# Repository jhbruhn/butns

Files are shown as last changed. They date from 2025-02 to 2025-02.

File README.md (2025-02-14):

# Overview

small grid 64 clone heavily based on previous work by [hugelton/btns](https://github.com/hugelton/Btns).

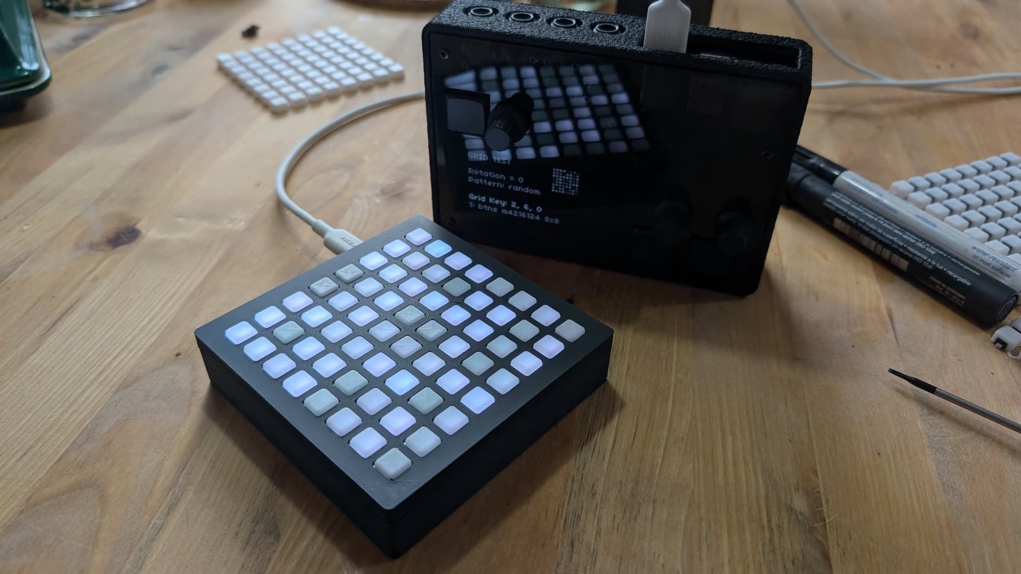
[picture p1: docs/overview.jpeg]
overview image


Uses a Rasperry Pi Pico Microcontroller, NeoPixel RGB LEDs (SK6812), cheap buttons and a 3d-printed case and button-overlay.
Includes hardware and firmware support for an optional tilt-sensor.

# Building

It is highly recommended to order the PCB assembled from JLCPCB. That assembly will include everything other than the parts in the BOM.

## BOM

| Part | Quantity | Source | Required | 
|---|---|---|---|
| PCB with components | 1 | JLCPCB, ordered with Gerber and Assembly files from latest release. Gerber: `butns-JLCPCB.zip`, BOM: `butns_bom_jlc.csv`, CPL: `butns_cpl_jlc.csv`. | yes | 
| Raspberry Pi Pico | 1 | Original Raspberry Pi Pico, or [USB-C Variant](https://de.aliexpress.com/item/1005007393927221.html) | yes | |
| M2.5x6 Button Head Screws | 5 | [M2.5x6](https://www.aliexpress.com/item/32810852732.html) | yes | 
| Case | 1 | 3d-printed (FDM). `case.stl` contains the top and bottom half. In the image, it is printed in black PLA, 0.2mm layerheight. | yes | 
| Button Matrix | 1 | 3d-printed (FDM). Print `buttons.stl` with white PLA and 0.12mm layerheight and no infill, 2 wall lines, concentric top infill. These should guide the LEDs light well. Optional: Add `buttons-black-blockers.stl` while importing as a multi-material print and print those in black to block light from neighboring buttons | yes (black blockers optional) | 
| Button TPU Case Inlay | 1 | 3d-printed (FDM). Print with TPU, perhaps in black. Will help against rattling of the buttons in the case. | no | 
| SMD 2.54" Pin Header 1x8 Type A | 1 | [1x8 Type A](https://www.aliexpress.com/item/1005005203849802.html) | no, for tilt | 
| MPU6050 module | 1 | [MPU6050 Module](https://www.aliexpress.com/item/1005006396343851.html) | no, for tilt | 

## Assembly

Flash microcontroller with `firmware.uf2`. Solder MCU and Pin-Header to PCB. Screw everything into the case. Done!

Hint: The cases Top half has one specific orientation where it fits nicely: The top-screw-posts of the top-half with the larger cutoaways go to the side opposite of the USB Connector.

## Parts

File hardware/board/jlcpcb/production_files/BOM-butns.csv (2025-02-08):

Comment | Designator | Footprint | LCSC | Quantity
100nF | C1,C10,C11,C12,C13,C14,C15,C16,C17,C18,C19,C2,C20,C21,C22,C23,C24,C25,C26,C27,C28,C29,C3,C30,C31,C32,C33,C34,C35,C36,C37,C38,C39,C4,C40,C41,C42,C43,C44,C45,C46,C47,C48,C49,C5,C50,C51,C52,C53,C54,C55,C56,C57,C58,C59,C6,C60,C61,C62,C63,C64,C65,C7,C8,C9 | C_0603_1608Metric | C14663 | 65
1N4148WS | D10,D11,D12,D13,D14,D15,D16,D17,D18,D19,D2,D20,D21,D22,D23,D24,D25,D26,D27,D28,D29,D3,D30,D31,D32,D33,D34,D35,D36,D37,D38,D39,D4,D40,D41,D42,D43,D44,D45,D46,D47,D48,D49,D5,D50,D51,D52,D53,D54,D55,D56,D57,D58,D59,D6,D60,D61,D62,D63,D64,D65,D7,D8,D9 | D_SOD-323 | C2128 | 64
SK6812-EC20 | D1,D100,D101,D102,D103,D104,D105,D106,D107,D108,D109,D110,D111,D112,D113,D114,D115,D116,D117,D118,D119,D120,D121,D122,D123,D124,D125,D126,D127,D128,D66,D67,D68,D69,D70,D71,D72,D73,D74,D75,D76,D77,D78,D79,D80,D81,D82,D83,D84,D85,D86,D87,D88,D89,D90,D91,D92,D93,D94,D95,D96,D97,D98,D99 | SK6812-EC20 | C2909058 | 64
SW_Push | SW1,SW10,SW11,SW12,SW13,SW14,SW15,SW16,SW17,SW18,SW19,SW2,SW20,SW21,SW22,SW23,SW24,SW25,SW26,SW27,SW28,SW29,SW3,SW30,SW31,SW32,SW33,SW34,SW35,SW36,SW37,SW38,SW39,SW4,SW40,SW41,SW42,SW43,SW44,SW45,SW46,SW47,SW48,SW49,SW5,SW50,SW51,SW52,SW53,SW54,SW55,SW56,SW57,SW58,SW59,SW6,SW60,SW61,SW62,SW63,SW64,SW7,SW8,SW9 | SW_Push_1P1T_XKB_TS-1187A | C318884 | 64
74LVC1G17 | U2 | SOT-23-5_HandSoldering | C7836 | 1
Conn_01x08 | J1 | PinHeader_1x08_P2.54mm_Vertical_SMD_Pin1Left |  | 1
Pico | U1 | RPi_Pico_SMD_TH |  | 1

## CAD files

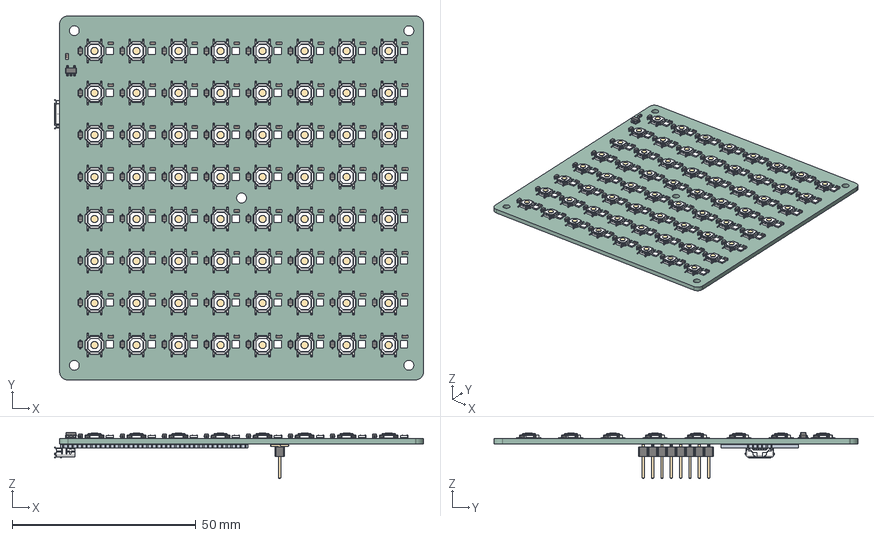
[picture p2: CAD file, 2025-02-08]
hardware/board/butns.step
100.4 x 99.0 x 12.6 mm
SK6812-EC20 x 64
C_0603_1608Metric x 65
TS-1187A v2 x 64
D_SOD_323 x 64
SOT_23_5
Raspberry Pi Pico v6
PinHeader_1x08_P254mm_Vertical_SMD_Pin1Left
butns_PCB

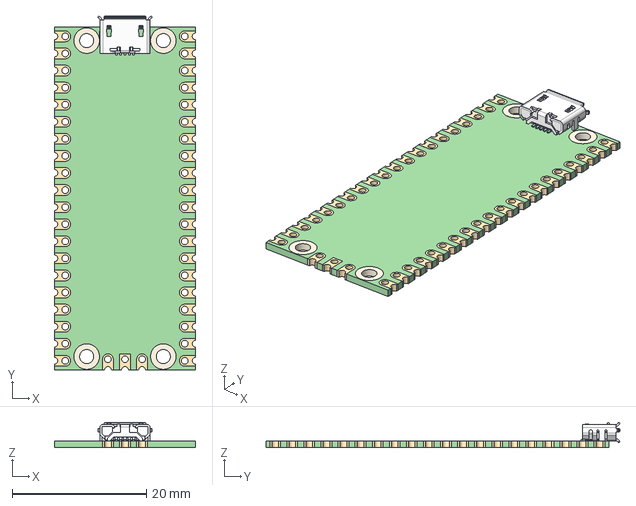
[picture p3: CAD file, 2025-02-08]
hardware/board/model/Raspberry Pi Pico.step
21.0 x 52.7 x 3.73 mm
PCB
Micro-USB_breakout v2

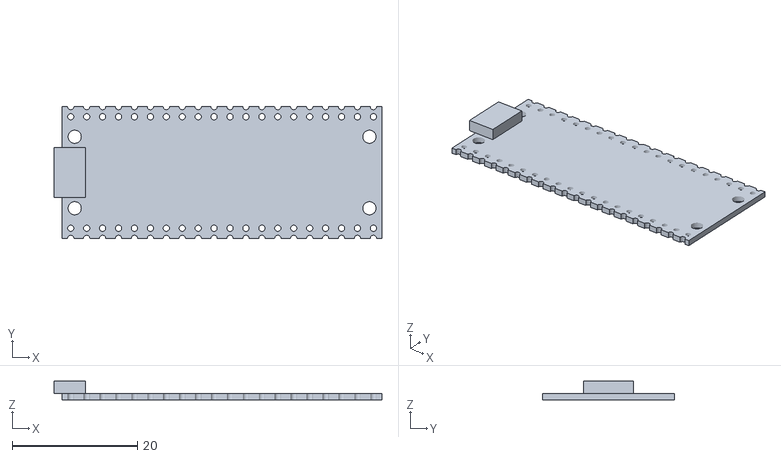
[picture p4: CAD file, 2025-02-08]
hardware/board/model/picow.stl
52.3 x 21.0 x 3.00

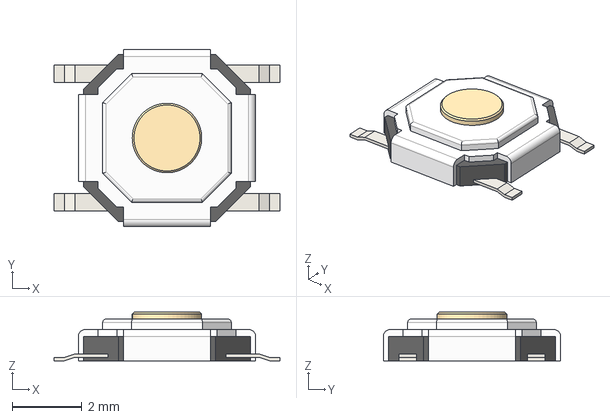
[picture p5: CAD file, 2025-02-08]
hardware/board/TS-1187A.step
6.50 x 5.10 x 1.40 mm

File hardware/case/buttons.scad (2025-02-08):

include <./roundedcube.scad>

height = 5.3;

s = 8.5;

px = 11.43;
py = 11.4;

inlayslack = 1;
rubberslack = .6;

inlayheight = 2.6 - inlayslack;

w = 0.42*3;
h = 0.12*3;

cross = true;

only_blockers = false;

only_inlay = false;

if(!only_blockers && !only_inlay) {
intersection() {
difference() {
union() {
for(x=[0:8-1]) for(y=[0:8-1])
translate([x * px, y * py, height / 2]) roundedcube([s, s, height], center = true, radius = 1.5, "zmax");

//translate([- s, -s, 0])cube([7 * px + s * 2, 7 * py + s * 2, inlayheight ]);
if (cross) {
for(x=[0:14])
translate([4 * px, (x-3) * py, h/2]) rotate([0, 0, 45]) cube([14*px, w, h], center = true);

for(x=[0:14])
translate([4 * px, (x-4) * py, h/2]) rotate([0, 0, -45]) cube([14*px, w, h], center = true);
} else {
for(x=[0:8-1]) for(y=[0:8-1]) {
translate([x * px, y * py - s / 4, h/2]) cube([12, w, h], center=true);
translate([x * px, y * py + s / 4, h/2]) cube([12, w, h], center=true);
translate([x * px - s / 4, y * py, h/2]) cube([w, 12, h], center=true);
translate([x * px + s / 4, y * py, h/2]) cube([w, 12, h], center=true);
}
}

}
translate([3.5 * px, 3.5 * py, 0]) cylinder(h = 20, d = 5.4, center = true);
translate([-px/2-1, -py/2-1, 0]) cylinder(h = 20, d = 5.8, center = true);
translate([7.5 * px+1, 7.5 * py+1, 0]) cylinder(h = 20, d = 5.8, center = true);
translate([-px/2-1, 7.5 * py+1, 0]) cylinder(h = 20, d = 5.8, center = true);
translate([7.5 * px+1, -py/2-1, 0]) cylinder(h = 20, d = 5.8, center = true);

}
translate([-s/2-1.5, -s/2-1.5, -1]) roundedcube([8*px-2.9+3, 8*py-2.9+3, 10], radius=1.5, center=false, "zmax");


}

for(x=[0:8-1]) for(y=[0:8-1])
translate([x * px + s/2, y * py, inlayheight / 2]) cube([3.25, s/3, inlayheight], center = true);

for(y=[0:8-1])
translate([-1 * px + s - 1, y * py, inlayheight / 2]) cube([2.75, s/4, inlayheight], center = true);
}
if (only_blockers && !only_inlay) {
color("blue")
for(x=[0:8-1]) for(y=[0:8-1])
translate([x * px - s/2+.15, y * py, (height - 2) / 2]) cube([.4, s-3, height - 2], center = true);
}

if (!only_blockers && only_inlay) {


color("blue") translate([0, 0, inlayheight]) difference() {
 translate([3.5*px, 3.5*py, (inlayslack - rubberslack) / 2]) cube([7*px, 7*py, inlayslack - rubberslack], center = true);
 
 for(x=[0:8-1]) for(y=[0:8-1])
translate([x * px, y * py, height / 2]) roundedcube([s+rubberslack, s + rubberslack, height], center = true, radius = 1.5, "zmax");

}
}

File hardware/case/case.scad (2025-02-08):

//-----------------------------------------------------------------------
// Yet Another Parameterized Projectbox generator
//
//  This is a box for <template>
//
//  Version 3.3.0 (2024-11-27)
//
// This design is parameterized based on the size of a PCB.
//
// For many/complex cutoutGrills, you might need to adjust
//  the max number of elements in OpenSCAD:
//
//      Preferences->Advanced->Turn off rendering at 250000 elements
//                                                   ^^^^^^
//
//-----------------------------------------------------------------------



include <./YAPP_Box/YAPPgenerator_v3.scad>

//---------------------------------------------------------
// This design is parameterized based on the size of a PCB.
//---------------------------------------------------------
// Note: length/lengte refers to X axis, 
//       width/breedte refers to Y axis,
//       height/hoogte refers to Z axis

/*
      padding-back|<------pcb length --->|<padding-front
                            RIGHT
        0    X-axis ---> 
        +----------------------------------------+   ---
        |                                        |    ^
        |                                        |   padding-right 
      Y |                                        |    v
      | |    -5,y +----------------------+       |   ---              
 B    a |         | 0,y              x,y |       |     ^              F
 A    x |         |                      |       |     |              R
 C    i |         |                      |       |     | pcb width    O
 K    s |         |                      |       |     |              N
        |         | 0,0              x,0 |       |     v              T
      ^ |    -5,0 +----------------------+       |   ---
      | |                                        |    padding-left
      0 +----------------------------------------+   ---
        0    X-as --->
                          LEFT
*/


//-- which part(s) do you want to print?
printBaseShell        = true;
printLidShell         = true;
printSwitchExtenders  = true;
printDisplayClips     = true;

// ********************************************************************
// The Following will be used as the first element in the pbc array

//Defined here so you can define the "Main" PCB using these if wanted
pcbLength           = 99; // front to back (X axis)
pcbWidth            = 99; // side to side (Y axis)
pcbThickness        = 1.6; 
standoffHeight      = 15; //-- How much the PCB needs to be raised from the base to leave room for solderings and whatnot
standoffDiameter    = 6;
standoffPinDiameter = 2.5;
standoffHoleSlack   = 0.4;

myPcb = "../butns.stl";

if ($preview)
{
  translate([pcbLength/2+2.5,pcbWidth/2+2.5,pcbThickness + standoffHeight]) 
  {
    rotate([0,0,90]) color("darkgray") import(myPcb);
  }
}
//===================================================================
// *** PCBs ***
// Printed Circuit Boards
//-------------------------------------------------------------------
//  Default origin =  yappCoordPCB : yappCoordBoxInside[0,0,0]
//
//  Parameters:
//   Required:
//    p(0) = name
//    p(1) = length
//    p(2) = width
//    p(3) = posx
//    p(4) = posy
//    p(5) = Thickness
//    p(6) = standoff_Height
//    p(7) = standoff_Diameter
//    p(8) = standoff_PinDiameter
//   Optional:
//    p(9) = standoff_HoleSlack (default to 0.4)

//The following can be used to get PCB values elsewhere in the script - not in pcb definition. 
//If "PCB Name" is omitted then "Main" is used
//  pcbLength           --> pcbLength("PCB Name")
//  pcbWidth            --> pcbWidth("PCB Name")
//  pcbThickness        --> pcbThickness("PCB Name") 
//  standoffHeight      --> standoffHeight("PCB Name") 
//  standoffDiameter    --> standoffDiameter("PCB Name") 
//  standoffPinDiameter --> standoffPinDiameter("PCB Name") 
//  standoffHoleSlack   --> standoffHoleSlack("PCB Name") 

pcb = 
[
  // Default Main PCB - DO NOT REMOVE the "Main" line.
  ["Main",              pcbLength,pcbWidth,    0,0,    pcbThickness,  standoffHeight, standoffDiameter, standoffPinDiameter, standoffHoleSlack]
];

//-------------------------------------------------------------------                            
//-- padding between pcb and inside wall
paddingFront        = .5;
paddingBack         = .5;
paddingRight        = 1.5;
paddingLeft         = .5;

//-- Edit these parameters for your own box dimensions
wallThickness       = 1.5;
basePlaneThickness  = 2;
lidPlaneThickness   = 2;

//-- Total height of box = lidPlaneThickness 
//                       + lidWallHeight 
//--                     + baseWallHeight 
//                       + basePlaneThickness
//-- space between pcb and lidPlane :=
//--      (bottonWallHeight+lidWallHeight) - (standoffHeight+pcbThickness)
baseWallHeight      = 18;
lidWallHeight       = 2;

//-- e where base and lid off box can overlap
//-- Make sure this isn't less than lidWallHeight
ridgeHeight         = 3;
ridgeSlack          = 0.2;
roundRadius         = 2.0;

// Box Types are 0-4 with 0 as the default
// 0 = All edges rounded with radius (roundRadius) above
// 1 = All edges sqrtuare
// 2 = All edges chamfered by (roundRadius) above 
// 3 = Square top and bottom edges (the ones that touch the build plate) and rounded vertical edges
// 4 = Square top and bottom edges (the ones that touch the build plate) and chamfered vertical edges
// 5 = Chanfered top and bottom edges (the ones that touch the build plate) and rounded vertical edges
boxType             = 3; // Default type 0

// Set the layer height of your printer
printerLayerHeight  = 0.2;


//---------------------------
//--     C O N T R O L     --
//---------------------------
// -- Render --
renderQuality             = 8;          //-> from 1 to 32, Default = 8

// --Preview --
previewQuality            = 5;          //-> from 1 to 32, Default = 5
showSideBySide            = false;       //-> Default = true
onLidGap                  = 0;  // tip don't override to animate the lid opening
colorLid                  = "YellowGreen";   
alphaLid                  = 1;
colorBase                 = "BurlyWood";
alphaBase                 = 1;
hideLidWalls              = false;      //-> Remove the walls from the lid : only if preview and showSideBySide=true 
hideBaseWalls             = false;      //-> Remove the walls from the base : only if preview and showSideBySide=true  
showOrientation           = true;       //-> Show the Front/Back/Left/Right labels : only in preview
showPCB                   = false;      //-> Show the PCB in red : only in preview 
showSwitches              = false;      //-> Show the switches (for pushbuttons) : only in preview 
showButtonsDepressed      = false;      //-> Should the buttons in the Lid On view be in the pressed position
showOriginCoordBox        = false;      //-> Shows red bars representing the origin for yappCoordBox : only in preview 
showOriginCoordBoxInside  = false;      //-> Shows blue bars representing the origin for yappCoordBoxInside : only in preview 
showOriginCoordPCB        = false;      //-> Shows blue bars representing the origin for yappCoordBoxInside : only in preview 
showMarkersPCB            = false;      //-> Shows black bars corners of the PCB : only in preview 
showMarkersCenter         = false;      //-> Shows magenta bars along the centers of all faces  
inspectX                  = 0;          //-> 0=none (>0 from Back)
inspectY                  = 6;          //-> 0=none (>0 from Right)
inspectZ                  = 0;          //-> 0=none (>0 from Bottom)
inspectXfromBack          = true;       //-> View from the inspection cut foreward
inspectYfromLeft          = true;       //-> View from the inspection cut to the right
inspectZfromBottom        = true;       //-> View from the inspection cut up
//---------------------------
//--     C O N T R O L     --
//---------------------------

//-------------------------------------------------------------------
//-------------------------------------------------------------------
// Start of Debugging config (used if not overridden in template)
// ------------------------------------------------------------------
// ------------------------------------------------------------------
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

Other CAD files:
hardware/case/roundedcube.scad

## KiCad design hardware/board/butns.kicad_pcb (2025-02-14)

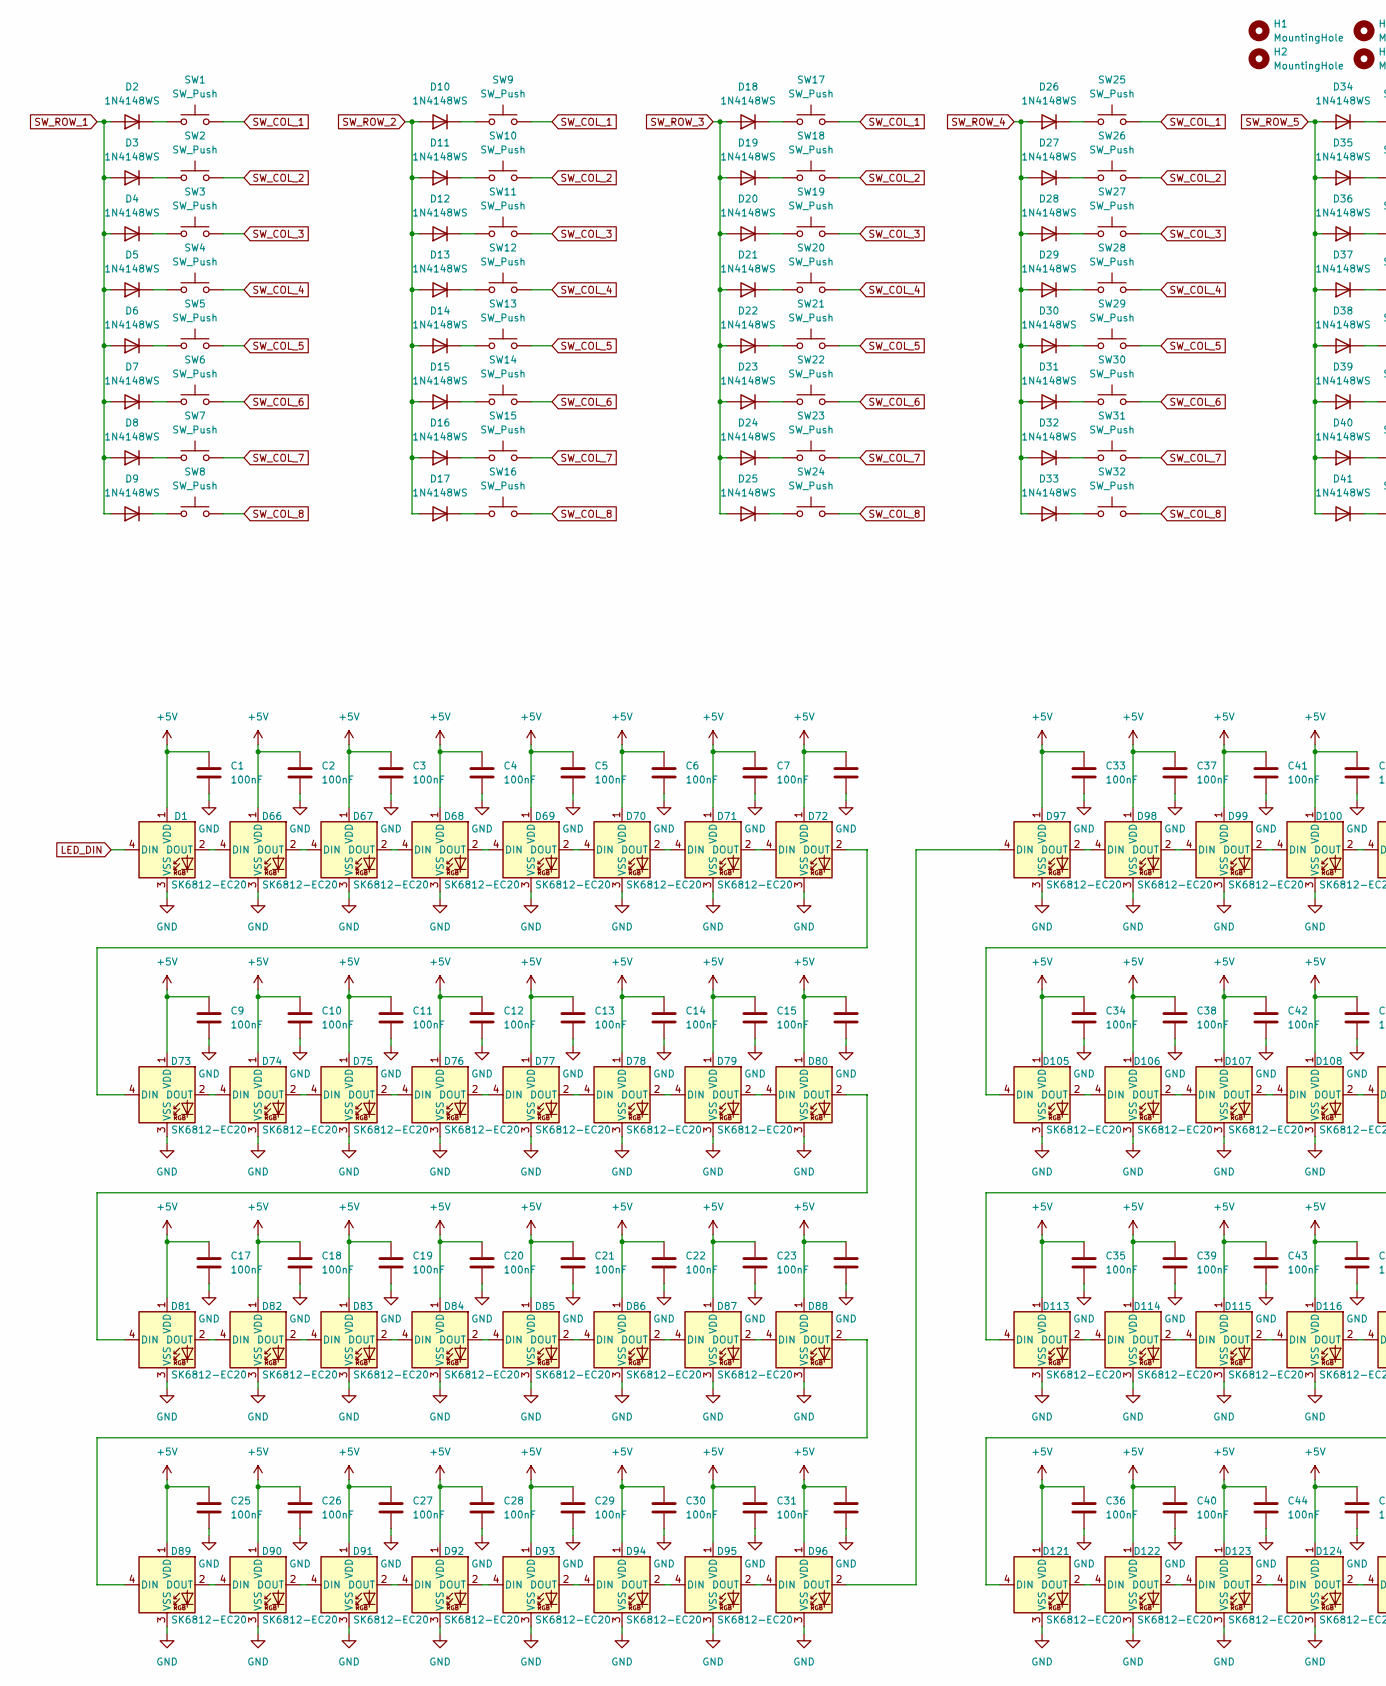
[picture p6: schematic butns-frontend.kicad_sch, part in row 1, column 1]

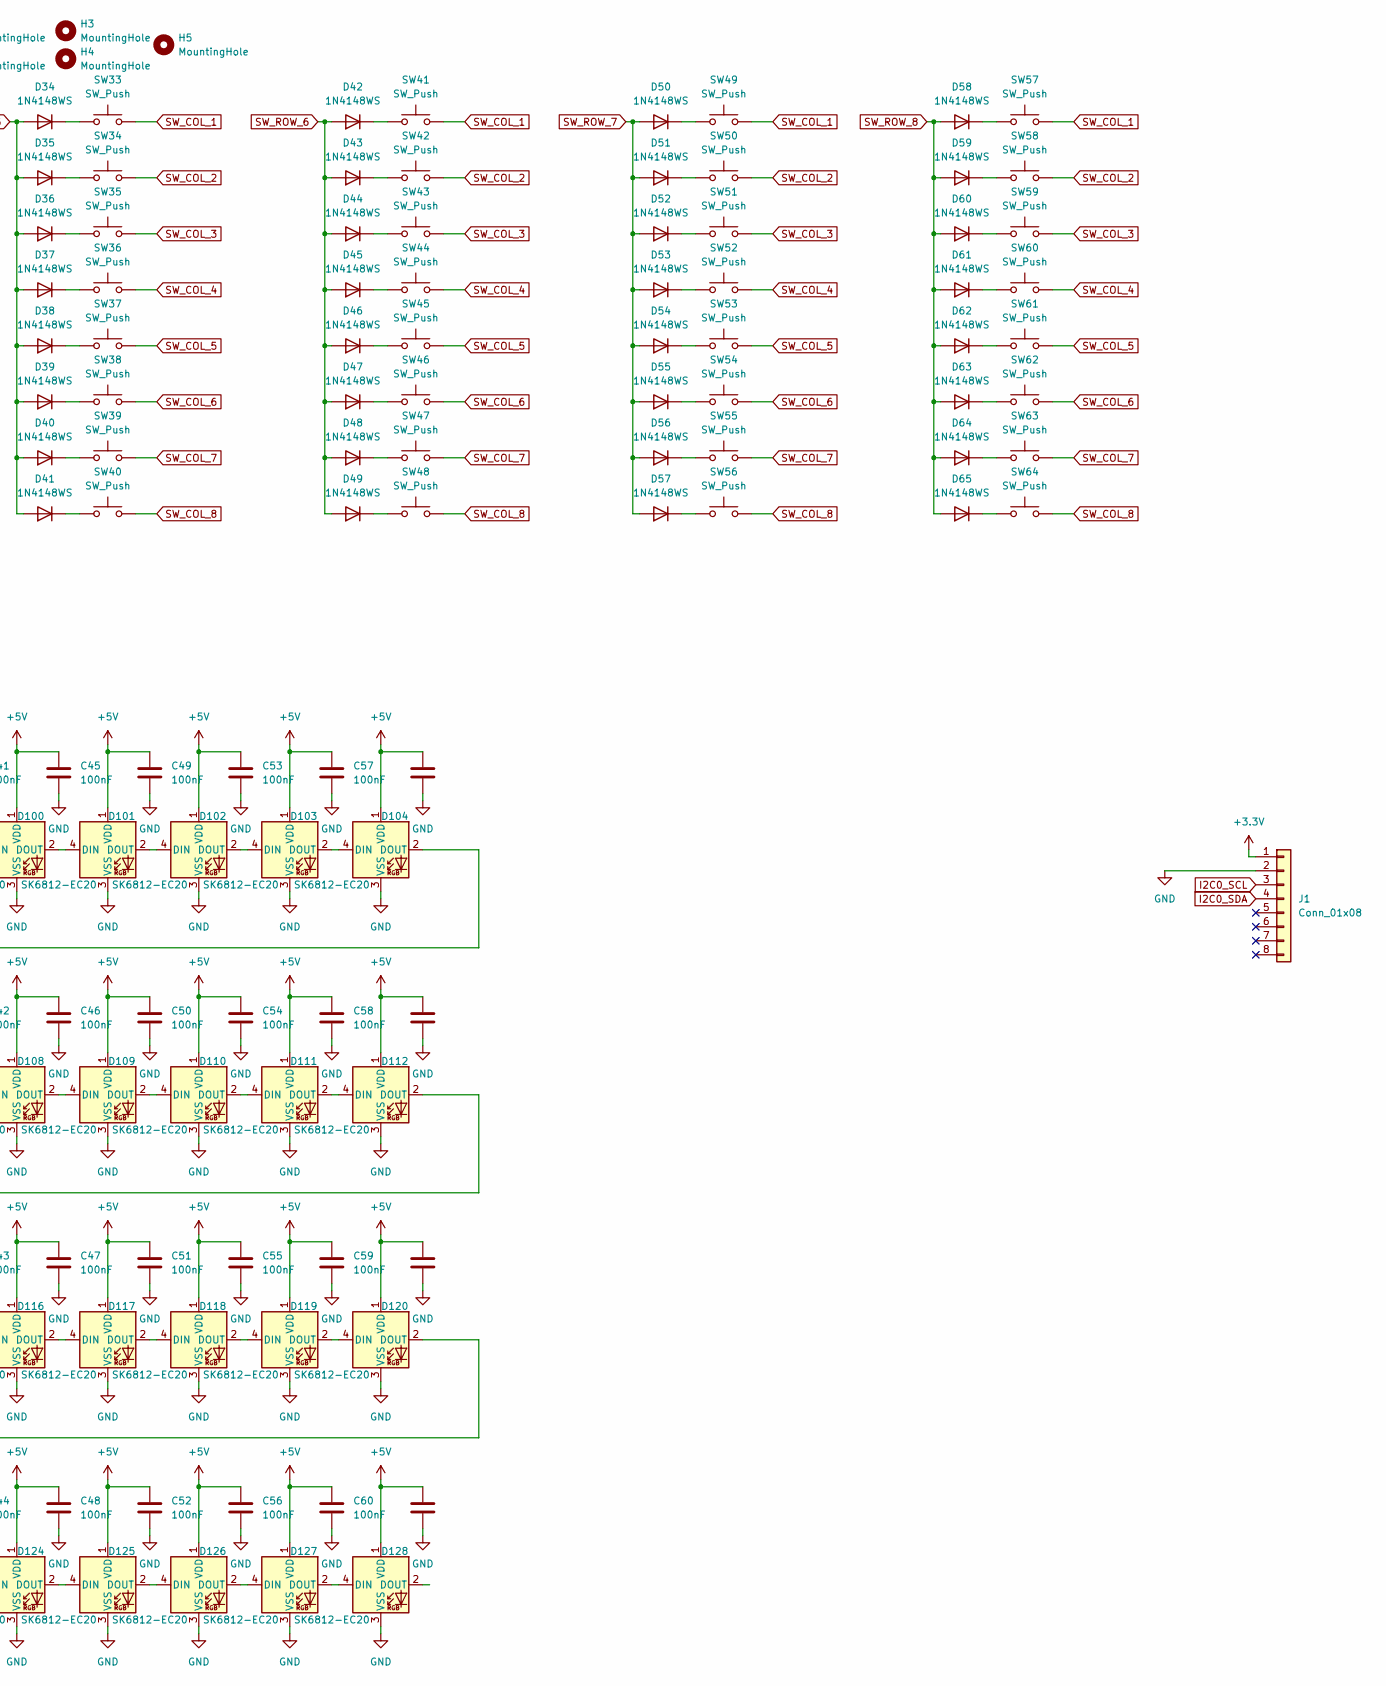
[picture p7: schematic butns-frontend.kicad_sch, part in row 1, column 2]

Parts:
C1, C2, C3, C4, C5, C6, C7, C8, C9, C10, C11, C12, C13, C14, C15, C16, C17, C18, C19, C20, C21, C22, C23, C24, C25, C26, C27, C28, C29, C30, C31, C32, C33, C34, C35, C36, C37, C38, C39, C40, C41, C42, C43, C44, C45, C46, C47, C48, C49, C50, C51, C52, C53, C54, C55, C56, C57, C58, C59, C60, C61, C62, C63, C64: 100nF; C_0603_1608Metric
D1, D66, D67, D68, D69, D70, D71, D72, D73, D74, D75, D76, D77, D78, D79, D80, D81, D82, D83, D84, D85, D86, D87, D88, D89, D90, D91, D92, D93, D94, D95, D96, D97, D98, D99, D100, D101, D102, D103, D104, D105, D106, D107, D108, D109, D110, D111, D112, D113, D114, D115, D116, D117, D118, D119, D120, D121, D122, D123, D124, D125, D126, D127, D128: SK6812-EC20
D2, D3, D4, D5, D6, D7, D8, D9, D10, D11, D12, D13, D14, D15, D16, D17, D18, D19, D20, D21, D22, D23, D24, D25, D26, D27, D28, D29, D30, D31, D32, D33, D34, D35, D36, D37, D38, D39, D40, D41, D42, D43, D44, D45, D46, D47, D48, D49, D50, D51, D52, D53, D54, D55, D56, D57, D58, D59, D60, D61, D62, D63, D64, D65: 1N4148WS; D_SOD-323
H1, H2, H3, H4, H5: MountingHole; MountingHole_2.7mm_M2.5
J1: Conn_01x08; PinHeader_1x08_P2.54mm_Vertical_SMD_Pin1Left
SW1, SW2, SW3, SW4, SW5, SW6, SW7, SW8, SW9, SW10, SW11, SW12, SW13, SW14, SW15, SW16, SW17, SW18, SW19, SW20, SW21, SW22, SW23, SW24, SW25, SW26, SW27, SW28, SW29, SW30, SW31, SW32, SW33, SW34, SW35, SW36, SW37, SW38, SW39, SW40, SW41, SW42, SW43, SW44, SW45, SW46, SW47, SW48, SW49, SW50, SW51, SW52, SW53, SW54, SW55, SW56, SW57, SW58, SW59, SW60, SW61, SW62, SW63, SW64: SW_Push; SW_Push_1P1T_XKB_TS-1187A

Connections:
+3.3V: J1.1; also elsewhere on the board
+5V: C1.1, C2.1, C3.1, C4.1, C5.1, C6.1, C7.1, C8.1, C9.1, C10.1, C11.1, C12.1, C13.1, C14.1, C15.1, C16.1, C17.1, C18.1, C19.1, C20.1, C21.1, C22.1, C23.1, C24.1, C25.1, C26.1, C27.1, C28.1, C29.1, C30.1, C31.1, C32.1, C33.1, C34.1, C35.1, C36.1, C37.1, C38.1, C39.1, C40.1, C41.1, C42.1, C43.1, C44.1, C45.1, C46.1, C47.1, C48.1, C49.1, C50.1, C51.1, C52.1, C53.1, C54.1, C55.1, C56.1, C57.1, C58.1, C59.1, C60.1, C61.1, C62.1, C63.1, C64.1, D1.1 (VDD), D66.1 (VDD), D67.1 (VDD), D68.1 (VDD), D69.1 (VDD), D70.1 (VDD), D71.1 (VDD), D72.1 (VDD), D73.1 (VDD), D74.1 (VDD), D75.1 (VDD), D76.1 (VDD), D77.1 (VDD), D78.1 (VDD), D79.1 (VDD), D80.1 (VDD), D81.1 (VDD), D82.1 (VDD), D83.1 (VDD), D84.1 (VDD), D85.1 (VDD), D86.1 (VDD), D87.1 (VDD), D88.1 (VDD), D89.1 (VDD), D90.1 (VDD), D91.1 (VDD), D92.1 (VDD), D93.1 (VDD), D94.1 (VDD), D95.1 (VDD), D96.1 (VDD), D97.1 (VDD), D98.1 (VDD), D99.1 (VDD), D100.1 (VDD), D101.1 (VDD), D102.1 (VDD), D103.1 (VDD), D104.1 (VDD), D105.1 (VDD), D106.1 (VDD), D107.1 (VDD), D108.1 (VDD), D109.1 (VDD), D110.1 (VDD), D111.1 (VDD), D112.1 (VDD), D113.1 (VDD), D114.1 (VDD), D115.1 (VDD), D116.1 (VDD), D117.1 (VDD), D118.1 (VDD), D119.1 (VDD), D120.1 (VDD), D121.1 (VDD), D122.1 (VDD), D123.1 (VDD), D124.1 (VDD), D125.1 (VDD), D126.1 (VDD), D127.1 (VDD), D128.1 (VDD); also elsewhere on the board
GND: C1.2, C2.2, C3.2, C4.2, C5.2, C6.2, C7.2, C8.2, C9.2, C10.2, C11.2, C12.2, C13.2, C14.2, C15.2, C16.2, C17.2, C18.2, C19.2, C20.2, C21.2, C22.2, C23.2, C24.2, C25.2, C26.2, C27.2, C28.2, C29.2, C30.2, C31.2, C32.2, C33.2, C34.2, C35.2, C36.2, C37.2, C38.2, C39.2, C40.2, C41.2, C42.2, C43.2, C44.2, C45.2, C46.2, C47.2, C48.2, C49.2, C50.2, C51.2, C52.2, C53.2, C54.2, C55.2, C56.2, C57.2, C58.2, C59.2, C60.2, C61.2, C62.2, C63.2, C64.2, D1.3 (VSS), D66.3 (VSS), D67.3 (VSS), D68.3 (VSS), D69.3 (VSS), D70.3 (VSS), D71.3 (VSS), D72.3 (VSS), D73.3 (VSS), D74.3 (VSS), D75.3 (VSS), D76.3 (VSS), D77.3 (VSS), D78.3 (VSS), D79.3 (VSS), D80.3 (VSS), D81.3 (VSS), D82.3 (VSS), D83.3 (VSS), D84.3 (VSS), D85.3 (VSS), D86.3 (VSS), D87.3 (VSS), D88.3 (VSS), D89.3 (VSS), D90.3 (VSS), D91.3 (VSS), D92.3 (VSS), D93.3 (VSS), D94.3 (VSS), D95.3 (VSS), D96.3 (VSS), D97.3 (VSS), D98.3 (VSS), D99.3 (VSS), D100.3 (VSS), D101.3 (VSS), D102.3 (VSS), D103.3 (VSS), D104.3 (VSS), D105.3 (VSS), D106.3 (VSS), D107.3 (VSS), D108.3 (VSS), D109.3 (VSS), D110.3 (VSS), D111.3 (VSS), D112.3 (VSS), D113.3 (VSS), D114.3 (VSS), D115.3 (VSS), D116.3 (VSS), D117.3 (VSS), D118.3 (VSS), D119.3 (VSS), D120.3 (VSS), D121.3 (VSS), D122.3 (VSS), D123.3 (VSS), D124.3 (VSS), D125.3 (VSS), D126.3 (VSS), D127.3 (VSS), D128.3 (VSS), J1.2; also elsewhere on the board
I2C0_SCL: J1.3; also elsewhere on the board
I2C0_SDA: J1.4; also elsewhere on the board
LED_DIN: D1.4 (DIN); also elsewhere on the board
unnamed: D1.2 (DOUT), D66.4 (DIN)
unnamed: D2.1 (K), SW1.1
unnamed: D3.1 (K), SW2.1
unnamed: D4.1 (K), SW3.1
unnamed: D5.1 (K), SW4.1
unnamed: D6.1 (K), SW5.1
unnamed: D7.1 (K), SW6.1
unnamed: D8.1 (K), SW7.1
unnamed: D9.1 (K), SW8.1
unnamed: D10.1 (K), SW9.1
unnamed: D11.1 (K), SW10.1
unnamed: D12.1 (K), SW11.1
unnamed: D13.1 (K), SW12.1
unnamed: D14.1 (K), SW13.1
unnamed: D15.1 (K), SW14.1
unnamed: D16.1 (K), SW15.1
unnamed: D17.1 (K), SW16.1
unnamed: D18.1 (K), SW17.1
unnamed: D19.1 (K), SW18.1
unnamed: D20.1 (K), SW19.1
unnamed: D21.1 (K), SW20.1
unnamed: D22.1 (K), SW21.1
unnamed: D23.1 (K), SW22.1
unnamed: D24.1 (K), SW23.1
unnamed: D25.1 (K), SW24.1
unnamed: D26.1 (K), SW25.1
unnamed: D27.1 (K), SW26.1
unnamed: D28.1 (K), SW27.1
unnamed: D29.1 (K), SW28.1
unnamed: D30.1 (K), SW29.1
unnamed: D31.1 (K), SW30.1
unnamed: D32.1 (K), SW31.1
unnamed: D33.1 (K), SW32.1
unnamed: D34.1 (K), SW33.1
unnamed: D35.1 (K), SW34.1
unnamed: D36.1 (K), SW35.1
unnamed: D37.1 (K), SW36.1
unnamed: D38.1 (K), SW37.1
unnamed: D39.1 (K), SW38.1
unnamed: D40.1 (K), SW39.1
unnamed: D41.1 (K), SW40.1
unnamed: D42.1 (K), SW41.1
unnamed: D43.1 (K), SW42.1
unnamed: D44.1 (K), SW43.1
unnamed: D45.1 (K), SW44.1
unnamed: D46.1 (K), SW45.1
unnamed: D47.1 (K), SW46.1
unnamed: D48.1 (K), SW47.1
unnamed: D49.1 (K), SW48.1
unnamed: D50.1 (K), SW49.1
unnamed: D51.1 (K), SW50.1
unnamed: D52.1 (K), SW51.1
unnamed: D53.1 (K), SW52.1
unnamed: D54.1 (K), SW53.1
unnamed: D55.1 (K), SW54.1
unnamed: D56.1 (K), SW55.1
unnamed: D57.1 (K), SW56.1
unnamed: D58.1 (K), SW57.1
unnamed: D59.1 (K), SW58.1
unnamed: D60.1 (K), SW59.1
unnamed: D61.1 (K), SW60.1
unnamed: D62.1 (K), SW61.1
unnamed: D63.1 (K), SW62.1
unnamed: D64.1 (K), SW63.1
unnamed: D65.1 (K), SW64.1
unnamed: D66.2 (DOUT), D67.4 (DIN)
unnamed: D67.2 (DOUT), D68.4 (DIN)
unnamed: D68.2 (DOUT), D69.4 (DIN)
unnamed: D69.2 (DOUT), D70.4 (DIN)
unnamed: D70.2 (DOUT), D71.4 (DIN)
unnamed: D71.2 (DOUT), D72.4 (DIN)
unnamed: D72.2 (DOUT), D73.4 (DIN)
unnamed: D73.2 (DOUT), D74.4 (DIN)
unnamed: D74.2 (DOUT), D75.4 (DIN)
unnamed: D75.2 (DOUT), D76.4 (DIN)
unnamed: D76.2 (DOUT), D77.4 (DIN)
unnamed: D77.2 (DOUT), D78.4 (DIN)
unnamed: D78.2 (DOUT), D79.4 (DIN)
unnamed: D79.2 (DOUT), D80.4 (DIN)
unnamed: D80.2 (DOUT), D81.4 (DIN)
unnamed: D81.2 (DOUT), D82.4 (DIN)
unnamed: D82.2 (DOUT), D83.4 (DIN)
unnamed: D83.2 (DOUT), D84.4 (DIN)
unnamed: D84.2 (DOUT), D85.4 (DIN)
unnamed: D85.2 (DOUT), D86.4 (DIN)
unnamed: D86.2 (DOUT), D87.4 (DIN)
unnamed: D87.2 (DOUT), D88.4 (DIN)
unnamed: D88.2 (DOUT), D89.4 (DIN)
unnamed: D89.2 (DOUT), D90.4 (DIN)
unnamed: D90.2 (DOUT), D91.4 (DIN)
unnamed: D91.2 (DOUT), D92.4 (DIN)
unnamed: D92.2 (DOUT), D93.4 (DIN)
unnamed: D93.2 (DOUT), D94.4 (DIN)
unnamed: D94.2 (DOUT), D95.4 (DIN)
unnamed: D95.2 (DOUT), D96.4 (DIN)
unnamed: D96.2 (DOUT), D97.4 (DIN)
unnamed: D97.2 (DOUT), D98.4 (DIN)
unnamed: D98.2 (DOUT), D99.4 (DIN)
unnamed: D99.2 (DOUT), D100.4 (DIN)
unnamed: D100.2 (DOUT), D101.4 (DIN)
unnamed: D101.2 (DOUT), D102.4 (DIN)
unnamed: D102.2 (DOUT), D103.4 (DIN)
unnamed: D103.2 (DOUT), D104.4 (DIN)
unnamed: D104.2 (DOUT), D105.4 (DIN)
unnamed: D105.2 (DOUT), D106.4 (DIN)
unnamed: D106.2 (DOUT), D107.4 (DIN)
unnamed: D107.2 (DOUT), D108.4 (DIN)
unnamed: D108.2 (DOUT), D109.4 (DIN)
unnamed: D109.2 (DOUT), D110.4 (DIN)
unnamed: D110.2 (DOUT), D111.4 (DIN)
unnamed: D111.2 (DOUT), D112.4 (DIN)
unnamed: D112.2 (DOUT), D113.4 (DIN)
unnamed: D113.2 (DOUT), D114.4 (DIN)
unnamed: D114.2 (DOUT), D115.4 (DIN)
unnamed: D115.2 (DOUT), D116.4 (DIN)
unnamed: D116.2 (DOUT), D117.4 (DIN)
unnamed: D117.2 (DOUT), D118.4 (DIN)
unnamed: D118.2 (DOUT), D119.4 (DIN)
unnamed: D119.2 (DOUT), D120.4 (DIN)
unnamed: D120.2 (DOUT), D121.4 (DIN)
unnamed: D121.2 (DOUT), D122.4 (DIN)
unnamed: D122.2 (DOUT), D123.4 (DIN)
unnamed: D123.2 (DOUT), D124.4 (DIN)
unnamed: D124.2 (DOUT), D125.4 (DIN)
unnamed: D125.2 (DOUT), D126.4 (DIN)
unnamed: D126.2 (DOUT), D127.4 (DIN)
unnamed: D127.2 (DOUT), D128.4 (DIN)
SW_COL_1: SW1.2, SW9.2, SW17.2, SW25.2, SW33.2, SW41.2, SW49.2, SW57.2; also elsewhere on the board
SW_COL_2: SW2.2, SW10.2, SW18.2, SW26.2, SW34.2, SW42.2, SW50.2, SW58.2; also elsewhere on the board
SW_COL_3: SW3.2, SW11.2, SW19.2, SW27.2, SW35.2, SW43.2, SW51.2, SW59.2; also elsewhere on the board
SW_COL_4: SW4.2, SW12.2, SW20.2, SW28.2, SW36.2, SW44.2, SW52.2, SW60.2; also elsewhere on the board
SW_COL_5: SW5.2, SW13.2, SW21.2, SW29.2, SW37.2, SW45.2, SW53.2, SW61.2; also elsewhere on the board
SW_COL_6: SW6.2, SW14.2, SW22.2, SW30.2, SW38.2, SW46.2, SW54.2, SW62.2; also elsewhere on the board
SW_COL_7: SW7.2, SW15.2, SW23.2, SW31.2, SW39.2, SW47.2, SW55.2, SW63.2; also elsewhere on the board
SW_COL_8: SW8.2, SW16.2, SW24.2, SW32.2, SW40.2, SW48.2, SW56.2, SW64.2; also elsewhere on the board
SW_ROW_1: D2.2 (A), D3.2 (A), D4.2 (A), D5.2 (A), D6.2 (A), D7.2 (A), D8.2 (A), D9.2 (A); also elsewhere on the board
SW_ROW_2: D10.2 (A), D11.2 (A), D12.2 (A), D13.2 (A), D14.2 (A), D15.2 (A), D16.2 (A), D17.2 (A); also elsewhere on the board
SW_ROW_3: D18.2 (A), D19.2 (A), D20.2 (A), D21.2 (A), D22.2 (A), D23.2 (A), D24.2 (A), D25.2 (A); also elsewhere on the board
SW_ROW_4: D26.2 (A), D27.2 (A), D28.2 (A), D29.2 (A), D30.2 (A), D31.2 (A), D32.2 (A), D33.2 (A); also elsewhere on the board
SW_ROW_5: D34.2 (A), D35.2 (A), D36.2 (A), D37.2 (A), D38.2 (A), D39.2 (A), D40.2 (A), D41.2 (A); also elsewhere on the board
SW_ROW_6: D42.2 (A), D43.2 (A), D44.2 (A), D45.2 (A), D46.2 (A), D47.2 (A), D48.2 (A), D49.2 (A); also elsewhere on the board
SW_ROW_7: D50.2 (A), D51.2 (A), D52.2 (A), D53.2 (A), D54.2 (A), D55.2 (A), D56.2 (A), D57.2 (A); also elsewhere on the board
SW_ROW_8: D58.2 (A), D59.2 (A), D60.2 (A), D61.2 (A), D62.2 (A), D63.2 (A), D64.2 (A), D65.2 (A); also elsewhere on the board

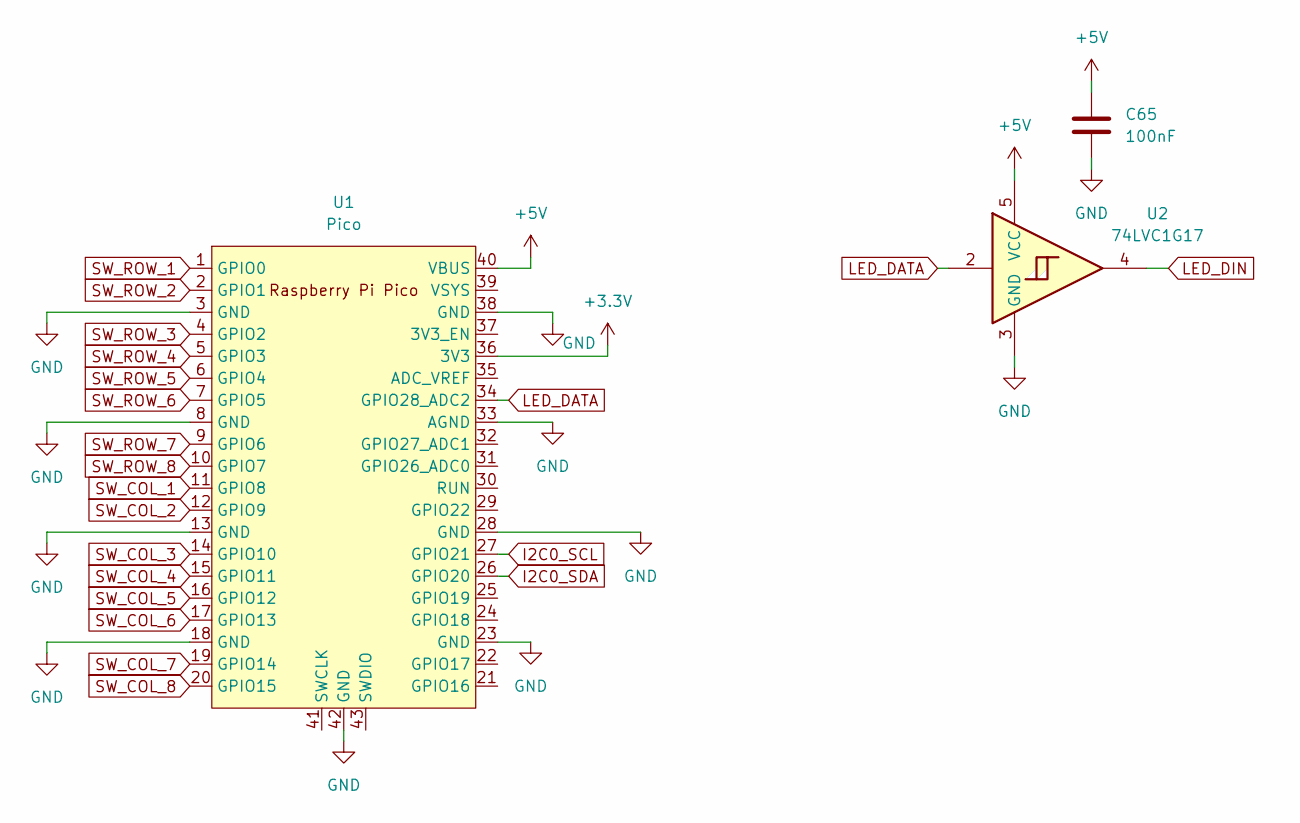
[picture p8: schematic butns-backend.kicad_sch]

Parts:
C65: 100nF; C_0603_1608Metric
U1: Pico; RPi_Pico_SMD_TH
U2: 74LVC1G17; SOT-23-5_HandSoldering

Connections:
+3.3V: U1.36 (3V3); also elsewhere on the board
+5V: C65.1, U1.40 (VBUS), U2.5 (VCC); also elsewhere on the board
GND: C65.2, U1.3 (GND), U1.8 (GND), U1.13 (GND), U1.18 (GND), U1.23 (GND), U1.28 (GND), U1.33 (AGND), U1.38 (GND), U1.42 (GND), U2.3 (GND); also elsewhere on the board
I2C0_SCL: U1.27 (GPIO21); also elsewhere on the board
I2C0_SDA: U1.26 (GPIO20); also elsewhere on the board
LED_DATA: U1.34 (GPIO28_ADC2), U2.2
LED_DIN: U2.4; also elsewhere on the board
SW_COL_1: U1.11 (GPIO8); also elsewhere on the board
SW_COL_2: U1.12 (GPIO9); also elsewhere on the board
SW_COL_3: U1.14 (GPIO10); also elsewhere on the board
SW_COL_4: U1.15 (GPIO11); also elsewhere on the board
SW_COL_5: U1.16 (GPIO12); also elsewhere on the board
SW_COL_6: U1.17 (GPIO13); also elsewhere on the board
SW_COL_7: U1.19 (GPIO14); also elsewhere on the board
SW_COL_8: U1.20 (GPIO15); also elsewhere on the board
SW_ROW_1: U1.1 (GPIO0); also elsewhere on the board
SW_ROW_2: U1.2 (GPIO1); also elsewhere on the board
SW_ROW_3: U1.4 (GPIO2); also elsewhere on the board
SW_ROW_4: U1.5 (GPIO3); also elsewhere on the board
SW_ROW_5: U1.6 (GPIO4); also elsewhere on the board
SW_ROW_6: U1.7 (GPIO5); also elsewhere on the board
SW_ROW_7: U1.9 (GPIO6); also elsewhere on the board
SW_ROW_8: U1.10 (GPIO7); also elsewhere on the board

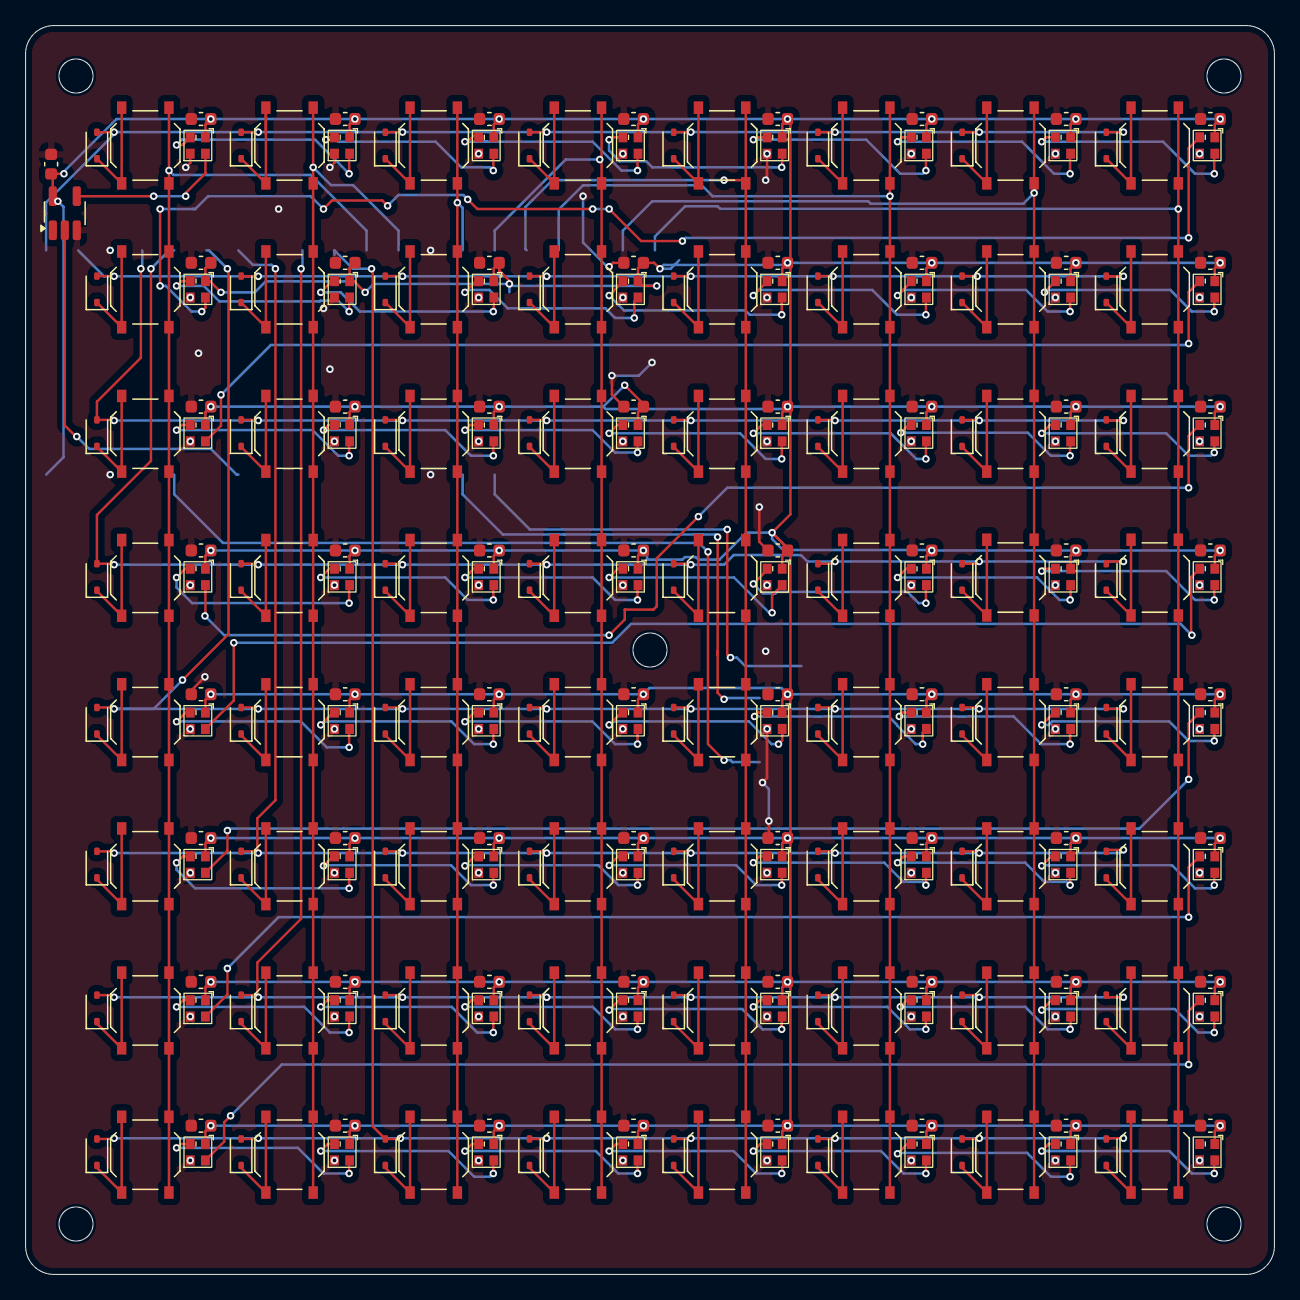
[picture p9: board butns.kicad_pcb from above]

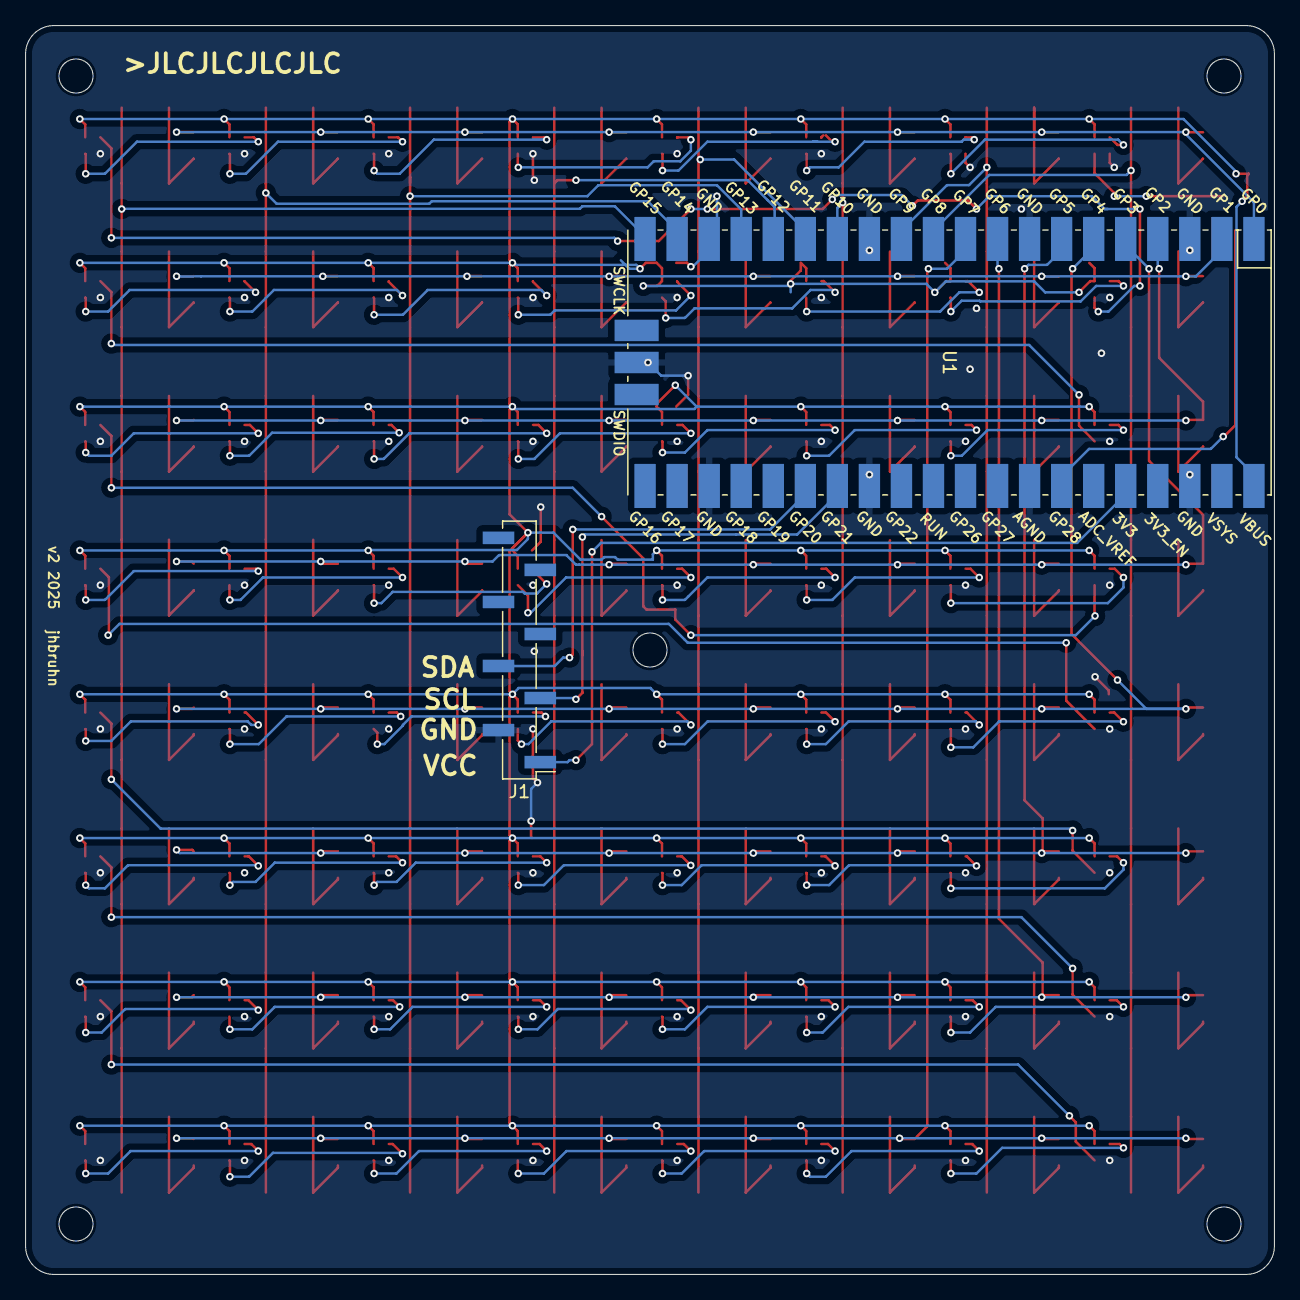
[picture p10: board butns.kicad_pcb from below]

Board: 2 copper layers, 99.0 x 99.0 mm, 265 parts (2 on the bottom side), 150 nets.

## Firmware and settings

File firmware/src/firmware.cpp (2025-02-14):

// Btns 0.6
// by Leo Kuroshita for Hügelton instruments, modified by jhbruhn.
// Modified to include MPU-6050 tilt support

#include "MonomeSerialDevice.h"
#include <Arduino.h>
#include <Adafruit_TinyUSB.h>
#include <Adafruit_MPU6050.h>
#include <Adafruit_Sensor.h>
#include <Adafruit_NeoPixel.h>
#include <Wire.h>

#define NUM_ROWS 8
#define NUM_COLS 8
#define BRIGHTNESS 127

#define DEFAULT_ROTATION 0
#define DEFAULT_FLIP_HORIZONTAL false
#define DEFAULT_FLIP_VERTICAL false

const uint8_t ROW_PINS[NUM_ROWS] = {0, 1, 2, 3, 4, 5, 6, 7};  // GPIO00-GPIO07
const uint8_t COL_PINS[NUM_COLS] = {8, 9, 10, 11, 12, 13, 14, 15};  // GPIO8-GPIO15
const uint8_t gammaTable[16] = { 0,  2,  3,  6,  11, 18, 25, 32, 41, 59, 70, 80, 92, 103, 115, 127}; 
const uint8_t gammaAdj = 2;

bool isInited = false;
String deviceID = "btns";
String serialNum = "m4216124";

char mfgstr[32] = "monome";
char prodstr[32] = "monome";
char serialstr[32] = "m4216124";

Adafruit_NeoPixel pixels(NUM_ROWS * 8, 28, NEO_GRB + NEO_KHZ800);

MonomeSerialDevice mdp;
Adafruit_MPU6050 mpu;

bool buttonStates[NUM_ROWS][NUM_COLS] = {0};

int gridRotation = DEFAULT_ROTATION;
bool flipHorizontal = DEFAULT_FLIP_HORIZONTAL;
bool flipVertical = DEFAULT_FLIP_VERTICAL;

bool hasTiltSensor = false;

void sendTiltData();
void updateLEDMatrix();
void scanButtonMatrix();
void mapButtonToLED(int buttonRow, int buttonCol, int &ledRow, int &ledCol);
bool detectGridOrientation();

void mapButtonToLED(int buttonRow, int buttonCol, int &ledRow, int &ledCol) {
    // Handle button to LED mapping based on rotation and flipping
    ledRow = buttonRow;
    ledCol = buttonCol;

    // Apply rotation
    switch (gridRotation) {
        case 0: // No rotation
            break;
        case 1: // 90 degree rotation
            {
                int temp = ledRow;
                ledRow = ledCol;
                ledCol = NUM_COLS - 1 - temp;
            }
            break;
        case 2: // 180 degree rotation
            ledRow = NUM_ROWS - 1 - ledRow;
            ledCol = NUM_COLS - 1 - ledCol;
            break;
        case 3: // 270 degree rotation
            {
                int temp = ledRow;
                ledRow = NUM_ROWS - 1 - ledCol;
                ledCol = temp;
            }
            break;
    }

    // Apply flipping
    if (flipHorizontal) ledCol = NUM_COLS - 1 - ledCol;
    if (flipVertical) ledRow = NUM_ROWS - 1 - ledRow;
}

bool detectGridOrientation() {
    bool buttonPressed = false;
    // Scan to check which button is pressed
    for (int col = 0; col < NUM_COLS; col++) {
        digitalWrite(COL_PINS[col], LOW);
        for (int row = 0; row < NUM_ROWS; row++) {
            if (!digitalRead(ROW_PINS[row])) {
                buttonPressed = true;
                // Set grid rotation based on pressed button
                if (row == 0 && col == 0) {
                    gridRotation = 0;
                } else if (row == 0 && col == NUM_COLS - 1) {
                    gridRotation = 1;
                } else if (row == NUM_ROWS - 1 && col == NUM_COLS - 1) {
                    gridRotation = 2;
                } else if (row == NUM_ROWS - 1 && col == 0) {
                    gridRotation = 3;
                }
                digitalWrite(COL_PINS[col], HIGH);
                return buttonPressed;
            }
        }
        digitalWrite(COL_PINS[col], HIGH);
    }
    // If no button is pressed, set default orientation
    gridRotation = DEFAULT_ROTATION;
    return buttonPressed;
}

void setup() {
    USBDevice.setManufacturerDescriptor(mfgstr);
    USBDevice.setProductDescriptor(prodstr);
    USBDevice.setSerialDescriptor(serialstr);

    pinMode(LED_BUILTIN, OUTPUT);

    for (int i = 0; i < NUM_ROWS; i++) {
        pinMode(ROW_PINS[i], INPUT_PULLUP);
    }
    for (int i = 0; i < NUM_COLS; i++) {
        pinMode(COL_PINS[i], OUTPUT);
        digitalWrite(COL_PINS[i], HIGH);
    }

    detectGridOrientation();

    mdp.isMonome = true;
    mdp.deviceID = deviceID;
    mdp.setupAsGrid(NUM_ROWS, NUM_COLS);

    isInited = true;
    mdp.poll();

    // Send grid size and rotation information
    mdp.sendSysSize();
    mdp.sendSysRotation();
    pixels.begin();

    // Initialize MPU-6050
    Wire.setSCL(21);
    Wire.setSDA(20);
    Wire.begin();

    if (mpu.begin()) {
        hasTiltSensor = true;
        Serial.println("MPU6050 Found!");

        mpu.setAccelerometerRange(MPU6050_RANGE_16_G);
        mpu.setFilterBandwidth(MPU6050_BAND_21_HZ);
    }
}

void loop() {
    static unsigned long lastCheck = 0;
    static unsigned long lastTiltCheck = 0;
    unsigned long currentMillis = millis();

    mdp.poll();

    if (currentMillis - lastCheck >= 15) {
        lastCheck = currentMillis;
        scanButtonMatrix();
        updateLEDMatrix();
    }

    // Send tilt data every 100ms
    if (hasTiltSensor && currentMillis - lastTiltCheck >= 100) {
        lastTiltCheck = currentMillis;
        sendTiltData();
    }
}

void scanButtonMatrix() {
    for (int row = 0; row < NUM_ROWS; row++) {
        for (int col = 0; col < NUM_COLS; col++) {
            digitalWrite(COL_PINS[col], LOW);
            bool currentState = !digitalRead(ROW_PINS[row]);
            digitalWrite(COL_PINS[col], HIGH);

            int ledRow, ledCol;
            mapButtonToLED(row, col, ledRow, ledCol);

            if (currentState != buttonStates[row][col]) {
                mdp.sendGridKey(ledCol, ledRow, currentState);
                buttonStates[row][col] = currentState;
            }
        }
    }
}

void updateLEDMatrix() {
    for (int row = 0; row < NUM_ROWS; row++) {
        for (int col = 0; col < NUM_COLS; col++) {
            int ledRow, ledCol;
            mapButtonToLED(row, col, ledRow, ledCol);
            uint8_t intensity = gammaTable[mdp.leds[row * NUM_ROWS + col]] * gammaAdj;
            pixels.setPixelColor(ledRow * NUM_ROWS + ledCol, pixels.Color(intensity / 2, intensity, intensity / 2));
        }
    }
    pixels.show();
}

void sendTiltData() {
    sensors_event_t a, g, temp;
    mpu.getEvent(&a, &g, &temp);

    // TODO: Include Rotation here?
    int16_t axis[3];
    axis[0] = (int16_t)(a.acceleration.x * 4) + 128;
    axis[1] = (int16_t)(-a.acceleration.y * 4) + 128;
    axis[2] = (int16_t)(a.acceleration.z * 4) + 128;

    int8_t *axisbytes = (int8_t *)axis;

    mdp.sendTiltEvent(0,axisbytes[0],axisbytes[1],axisbytes[2],axisbytes[3],axisbytes[4],axisbytes[5]);
}

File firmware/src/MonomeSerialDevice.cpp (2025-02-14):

#include "MonomeSerialDevice.h"
#include "debug.h"

MonomeSerialDevice::MonomeSerialDevice() {}

void MonomeSerialDevice::initialize() {
  active = false;
  isMonome = false;
  isGrid = true;
  rows = 0;
  columns = 0;
  encoders = 0;
  //clearQueue();
  clearAllLeds();
  arcDirty = false;
  gridDirty = false;
}

void MonomeSerialDevice::setupAsGrid(uint8_t _rows, uint8_t _columns) {
  initialize();
  active = true;
  isMonome = true;
  isGrid = true;
  rows = _rows;
  columns = _columns;
  gridDirty = true;
  debugfln(INFO, "GRID rows: %d columns %d", rows, columns);
}

void MonomeSerialDevice::setupAsArc(uint8_t _encoders) {
  initialize();
  active = true;
  isMonome = true;
  isGrid = false;
  encoders = _encoders;
  arcDirty = true;
  debugfln(INFO, "ARC encoders: %d", encoders);
}

void MonomeSerialDevice::setTiltActive(uint8_t sensor, bool active) {
  if (sensor < 4) {
    tiltActive[sensor] = active;
  }
}

void MonomeSerialDevice::sendTiltEvent(uint8_t sensor, int8_t xh,int8_t xl,int8_t yh,int8_t yl,int8_t zh,int8_t zl) {
    if (sensor < 4 && tiltActive[sensor]) {

        Serial.write((uint8_t)0x81);  // tiltイベントのプレフィックス
        Serial.write(sensor);
        Serial.write((int8_t)xh);
        Serial.write((int8_t)xl);
        Serial.write((int8_t)yh);
        Serial.write((int8_t)yl);
        Serial.write((int8_t)zh);
        Serial.write((int8_t)zl);
    }
}


void MonomeSerialDevice::getDeviceInfo() {
  //debugln(INFO, "MonomeSerialDevice::getDeviceInfo");
  Serial.write(uint8_t(0));
}

void MonomeSerialDevice::poll() {
  //while (isMonome && Serial.available()) { processSerial(); };
  if (Serial.available()) {
    processSerial();
  }
  //Serial.println("processSerial");
}


void MonomeSerialDevice::setAllLEDs(int value) {
  for (int i = 0; i < MAXLEDCOUNT; i++) leds[i] = value;
}

void MonomeSerialDevice::setGridLed(uint8_t x, uint8_t y, uint8_t level) {
  //    int index = x + (y * columns);
  //    if (index < MAXLEDCOUNT) leds[index] = level;

  if (x < columns && y < rows) {
    uint32_t index = y * columns + x;
    leds[index] = level;
  }
  //debugfln(INFO, "LED index: %d x %d y %d", index, x, y);
}

void MonomeSerialDevice::clearGridLed(uint8_t x, uint8_t y) {
  setGridLed(x, y, 0);
  //Serial.println("clearGridLed");
}

void MonomeSerialDevice::setArcLed(uint8_t enc, uint8_t led, uint8_t level) {
  int index = led + (enc << 6);
  if (index < MAXLEDCOUNT) leds[index] = level;
  //Serial.println("setArcLed");
}

void MonomeSerialDevice::clearArcLed(uint8_t enc, uint8_t led) {
  setArcLed(enc, led, 0);
  //Serial.println("clearArcLed");
}

void MonomeSerialDevice::clearAllLeds() {
  for (int i = 0; i < MAXLEDCOUNT; i++) leds[i] = 0;
  //Serial.println("clearAllLeds");
}

void MonomeSerialDevice::clearArcRing(uint8_t ring) {
  for (int i = ring << 6, upper = i + 64; i < upper; i++) leds[i] = 0;
  //Serial.println("clearArcRing");
}

void MonomeSerialDevice::refreshGrid() {
  gridDirty = true;
  //Serial.println("refreshGrid");
}

void MonomeSerialDevice::refreshArc() {
  arcDirty = true;
  //Serial.println("refreshArc");
}

void MonomeSerialDevice::sendSysSize() {
  Serial.write((uint8_t)0x05);  // system / get grid size
  Serial.write((uint8_t)columns);
  Serial.write((uint8_t)rows);
}

void MonomeSerialDevice::sendSysRotation() {
  // Note: The original Monome protocol doesn't have a direct command for rotation.
  // This is a custom implementation. You may need to adjust how the host interprets this.
  Serial.write((uint8_t)0x0F);  // Using 0x0F (system / report firmware version) as a custom command
  Serial.write((uint8_t)0xF0);  // Custom identifier for rotation
  Serial.write((uint8_t)gridRotation);
}

void MonomeSerialDevice::refresh() {
  /*
    uint8_t buf[35];
    int ind, led;

    if (gridDirty) {
        //Serial.println("gridDirty");
        buf[0] = 0x1A;
        buf[1] = 0;
        buf[2] = 0;

        ind = 3;
        for (int y = 0; y < 8; y++)
            for (int x = 0; x < 8; x += 2) {
                led = (y << 4) + x;
                buf[ind++] = (leds[led] << 4) | leds[led + 1];
            }
        Serial.write(buf, 35);
        
        ind = 3;
        buf[1] = 8;
        for (int y = 0; y < 8; y++)
            for (int x = 8; x < 16; x += 2) {
                led = (y << 4) + x;
                buf[ind++] = (leds[led] << 4) | leds[led + 1];
            }
        Serial.write(buf, 35);
        
        ind = 3;
        buf[1] = 0;
        buf[2] = 8;
        for (int y = 8; y < 16; y++)
            for (int x = 0; x < 8; x += 2) {
                led = (y << 4) + x;
                buf[ind++] = (leds[led] << 4) | leds[led + 1];
            }
        Serial.write(buf, 35);

        ind = 3;
        buf[1] = 8;
        for (int y = 8; y < 16; y++)
            for (int x = 8; x < 16; x += 2) {
                led = (y << 4) + x;
                buf[ind++] = (leds[led] << 4) | leds[led + 1];
            }
        Serial.write(buf, 35);
        
        gridDirty = false;
    }

    if (arcDirty) {
        //Serial.print("arcDirty");
        buf[0] = 0x92;

        buf[1] = 0;
        ind = 2;
        for (led = 0; led < 64; led += 2)
            buf[ind++] = (leds[led] << 4) | leds[led + 1];
        Serial.write(buf, 34);
        
        buf[1] = 1;
        ind = 2;
        for (led = 64; led < 128; led += 2)
            buf[ind++] = (leds[led] << 4) | leds[led + 1];
        Serial.write(buf, 34);

        buf[1] = 2;
        ind = 2;
        for (led = 128; led < 192; led += 2)
            buf[ind++] = (leds[led] << 4) | leds[led + 1];
        Serial.write(buf, 34);
        
        buf[1] = 3;
        ind = 2;
        for (led = 192; led < 256; led += 2)
            buf[ind++] = (leds[led] << 4) | leds[led + 1];
        Serial.write(buf, 34);
        
        buf[1] = 4;
        ind = 2;
        for (led = 256; led < 320; led += 2)
            buf[ind++] = (leds[led] << 4) | leds[led + 1];
        Serial.write(buf, 34);

        buf[1] = 5;
        ind = 2;
        for (led = 320; led < 384; led += 2)
            buf[ind++] = (leds[led] << 4) | leds[led + 1];
        Serial.write(buf, 34);

        buf[1] = 6;
        ind = 2;
        for (led = 384; led < 448; led += 2)
            buf[ind++] = (leds[led] << 4) | leds[led + 1];
        Serial.write(buf, 34);

        buf[1] = 7;
        ind = 2;
        for (led = 448; led < 512; led += 2)
            buf[ind++] = (leds[led] << 4) | leds[led + 1];
        Serial.write(buf, 34);

        arcDirty = 0;
    }
*/
}
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

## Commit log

2025-02-08 Add board option
2025-02-08 Switch to pio
2025-02-08 Correctly move include files
    [firmware.cpp]
2025-02-08 Move files around, add case build job test
    [BOM-butns.csv, Raspberry Pi Pico.step, TS-1187A.step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]
2025-02-08 Rename case stls workflow
2025-02-08 Add parameter sets and jobs for buttons
    [buttons.scad]
2025-02-08 remove remains
    [base.stl, buttons-inly.stl, buttons-lessbleed.stl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]
2025-02-08 Add CI for kicad
2025-02-14 Implement Tilt Sensor support
2025-02-14 Remove Buttons Silkscreen name, update version
    [butns.kicad_pcb]
2025-02-14 Add hint on top case orientation
2025-02-14 Remove last column from bom
